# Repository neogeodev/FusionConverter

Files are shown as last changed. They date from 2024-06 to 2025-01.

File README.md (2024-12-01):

# FusionConverter

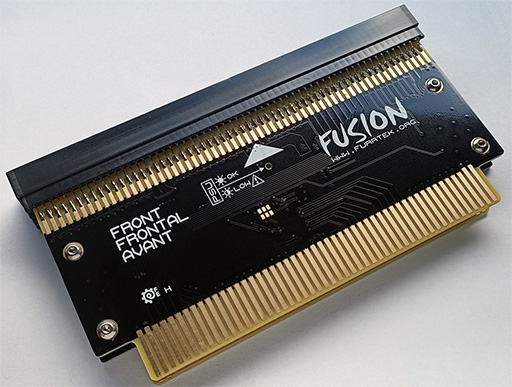
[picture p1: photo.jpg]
Fusion converter


Ready to use unbranded PCB GERBERs, BOM, Verilog and bitstream files.

Compatibility list: https://wiki.neogeodev.org/index.php?title=Fusion_converter

How to build:

* Order both PCBs with the following options: 2-layers 1.6mm thickness FR4, ENIG or hard gold fingers, edge bevelling.
* Order the components listed in `BOM.txt`. If you don't want the voltage supervision function, leave out CHA U3, R1 and D1.
* Bend the card edge connectors pins inwards to reduce their spacing and slide the boards between the rows.
* Solder everything.
* Program the CPLD with fusion_vsense.jed or fusion_vsense.svf. JTAG connections: see `JTAG.png`. The board MUST be powered externally during programming, the programming cable doesn't provide power.
* Wire the "RESET" pads on both boards together with a small wire.
* Use 8 screws and 4 standoffs to assemble both boards together.

The shell is optional. It can be printed with any method (FDM, SLA...)

# Note to JGO

* You went through the trouble of cloning an open-hardware project when you could just have used these files.
* You're not respecting the license.
* You lied about designing it yourself.
* If you cloned a device without paying attention to its open-source nature, that means you would also clone closed-source devices without caring.

From all the people who create things and share them for free: Fuck you.

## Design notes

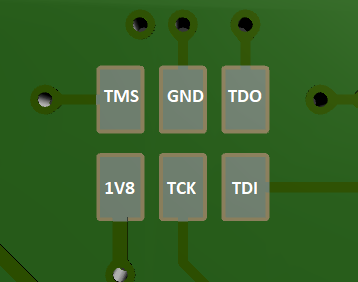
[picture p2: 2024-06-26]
JTAG.png

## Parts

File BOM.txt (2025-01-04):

CHA board:
Jx: Card edge connector 2*60pin 2.54mm pitch Sullins EZC60DCTT or EDAC 345-120-520-201
R1: Resistor 1k 0603
C1, C3-C6: MLCC 100nF 10V X7R 0603
C2: Tantalum capacitor 22uF 16V case C
U1: Dual output LDO 1.8V 3.3V AP7312-1833W6
U2: CPLD Lattice LC4064ZE-7TN100
U3: Voltage detector 4.8V APX803Lxx-48SA (xx = any)
D1: 1206 red LED

PROG board:
Jx: Card edge connector 2*60pin 2.54mm pitch Sullins EZC60DCTT or EDAC 345-120-520-201
R1: Resistor 1k 0603
C1-C3: MLCC 100nF 10V X7R 0603
C4: Tantalum capacitor 22uF 16V case C
U1, U2: Octal bus transceiver 74HC245 TSSOP20
U3: Quad 2-input AND gates 74HC08, 74AHC08 or 74HCT08 TSSOP14

Mechanical:
8x M3x4mm BHC screws, or M3x6mm if using shell
4x Hex 8mm standoffs

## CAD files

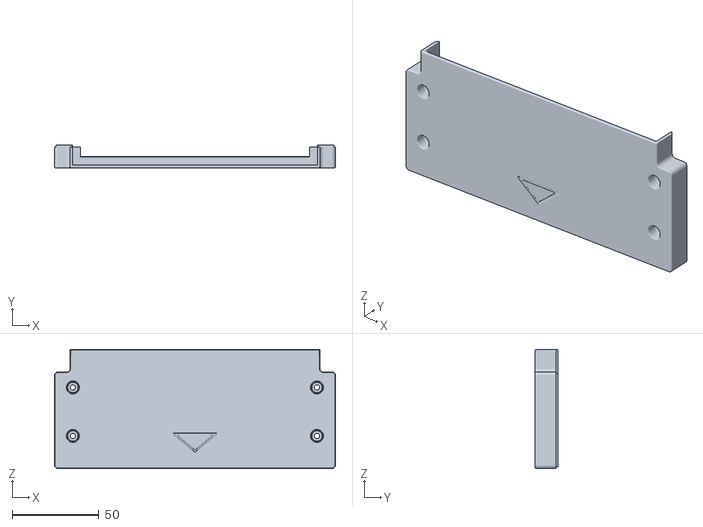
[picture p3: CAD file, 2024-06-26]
ShellA.STL
162.0 x 13.0 x 68.7

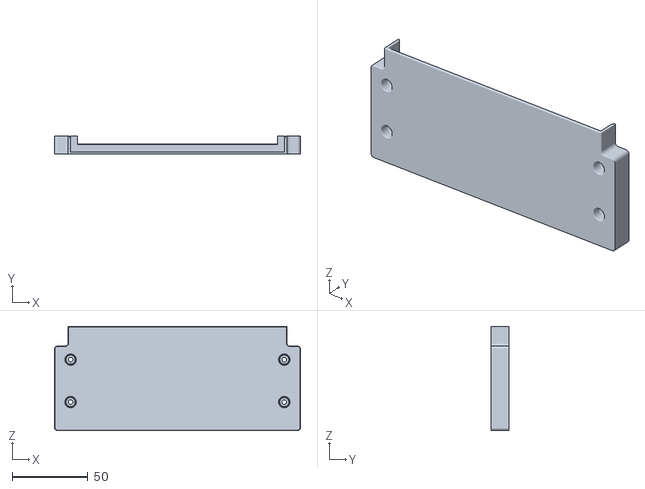
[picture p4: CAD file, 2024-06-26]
ShellB.STL
162.0 x 12.0 x 68.7

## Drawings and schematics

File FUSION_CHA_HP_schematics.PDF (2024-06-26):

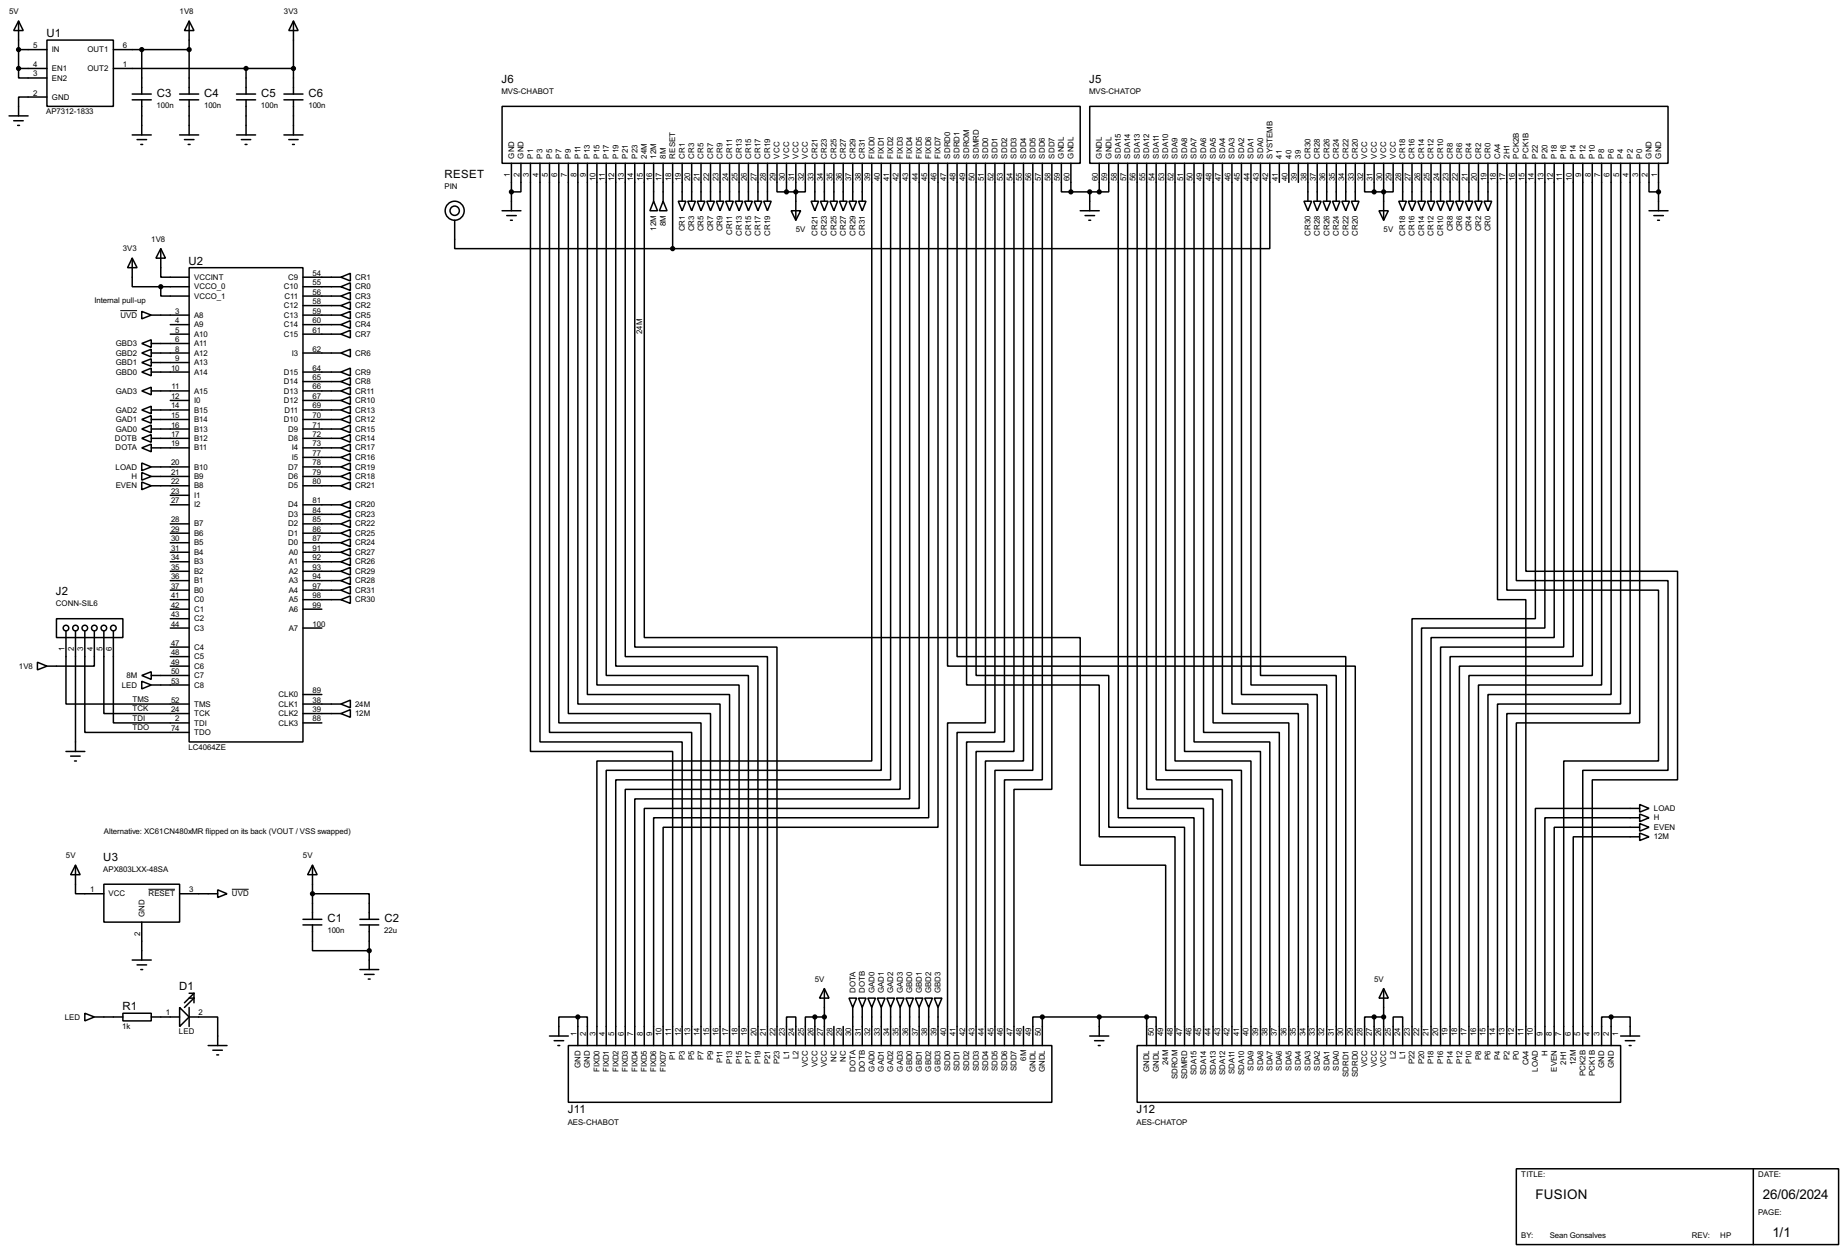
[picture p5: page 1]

8M LED TMS

TCK

Alternative: XC61CN480xMR flipped on its back (VOUT / VSS swapped)

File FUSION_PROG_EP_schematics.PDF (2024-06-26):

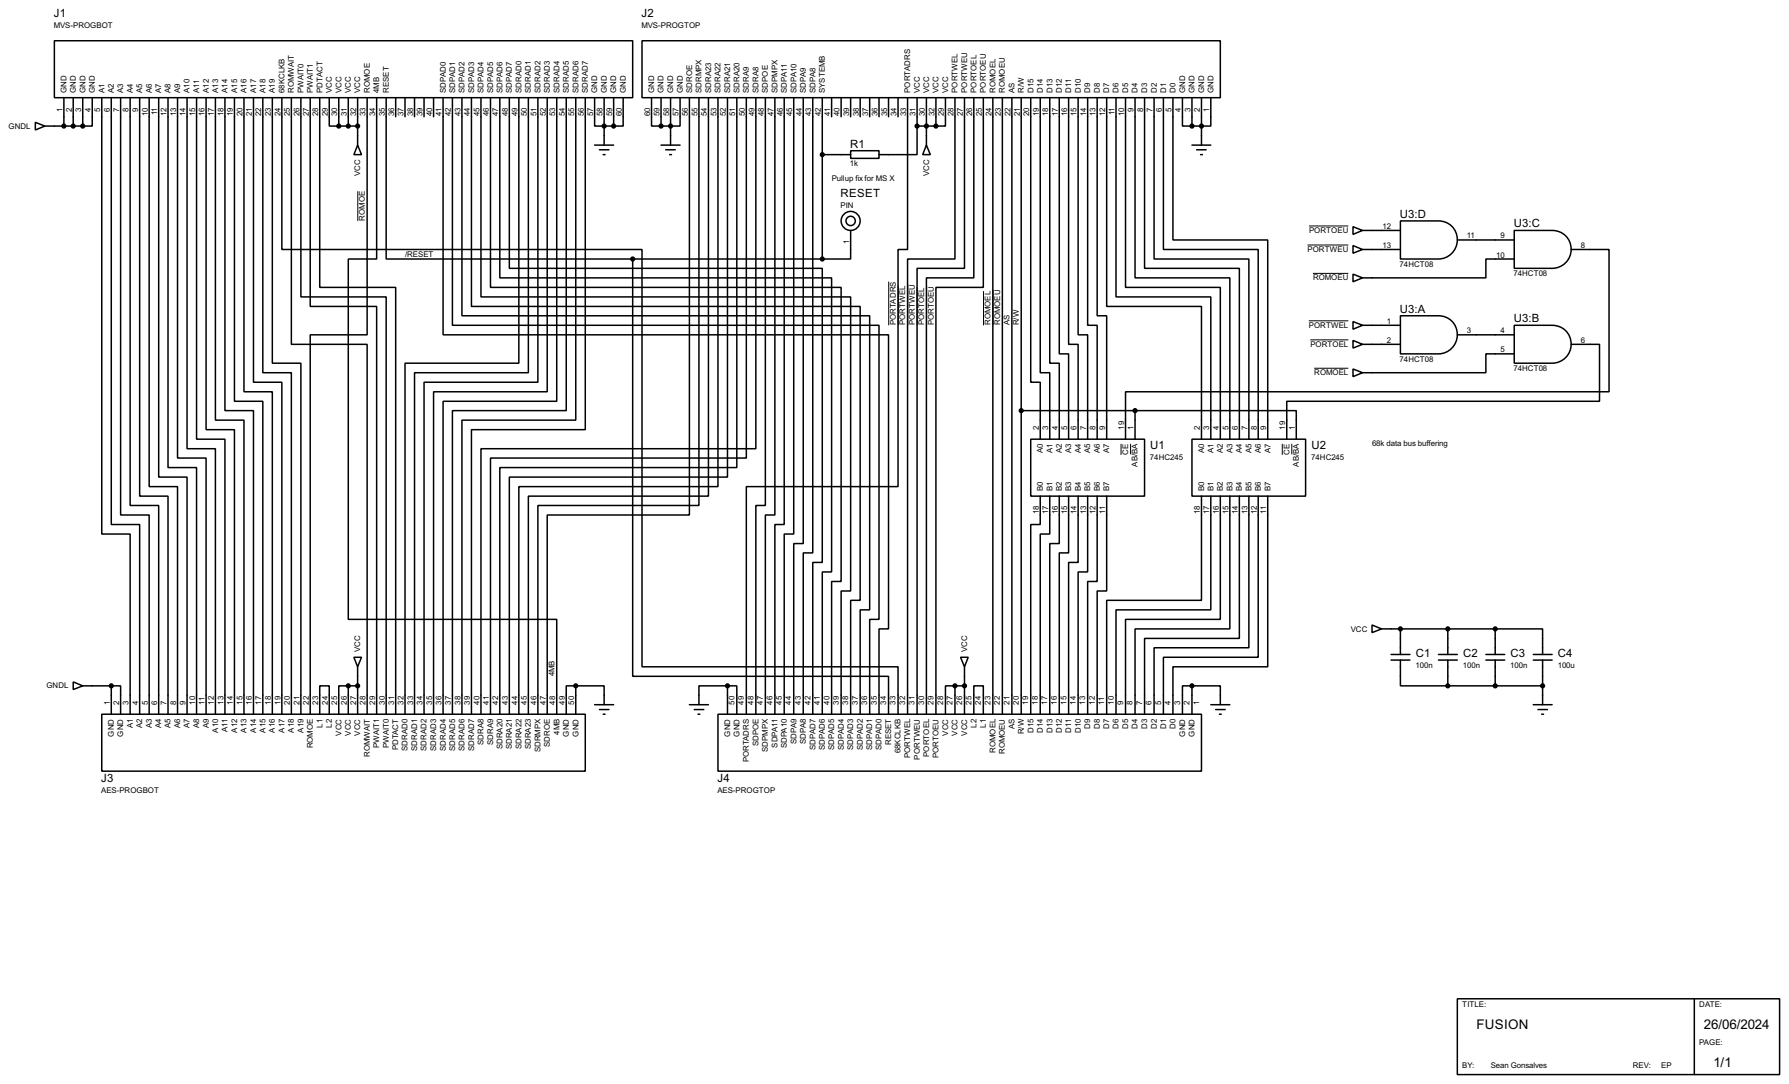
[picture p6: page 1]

Pullup fix for MS X

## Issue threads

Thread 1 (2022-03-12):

BOM

RastaJedi, 2022-03-12:
I see about 7 pads for capacitors on both boards, including the through-hole ones. I see from many pictures of your fusion that the through-hole is not populated. I still see three caps in the front, and two on the back, but the BOM has only two caps listed. I think the BOM is incomplete? Please advise =). Trying to make one for personal use.

furrtek, 2022-03-17:
BOM and JTAG info updated, sorry for the wait :)

RastaJedi, 2022-03-17:
No worries! Thanks so much for the update! Really appreciate it!

Closed 2024-12-01.

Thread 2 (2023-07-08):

Compiling the CPLD Firmware

Retrofletch, 2023-07-08:
Hello
i have built two of these and they both act the same, i get only the normal blue screen and rarely i get a verry garbled Neo geo logo trying to show.

When i tried to compile the firmware in Quartus i got many errors in regards to timings as there is no SDC file, i tried to make my own and got rid of almost all the complaints but i was more or less just making guesses so im not sure i did it correctly.

basicly im not at all confident in my compiled firmware and i suspect that is the issue as i have double checked soldering.

Is there a more complete set of quartus files to work with? or even better a confirmed and known working file to program the cpld with?

Looks like original files were made in quartus 12, i was not able to find that so i was using quartus 13, maybe thats a problem?
have tested several mvs cartidges.

reset wire is soldered in.

not sure how to proceed, any help appreciated
thanks

furrtek, 2023-07-08:
Hello,

The files are known to work, the timing warnings given by Quartus can be ignored as the clocks are well under the fmax.
Blue screen means the console wasn't able to read the program ROMs, which the CPLD doesn't mess with. Most certainly several bad contacts.

Retrofletch, 2023-07-08:
Hmm yes, but if i plug in a AES cart it will boot and all contacts both on the fusionconverter and the mvs cartridges have been cleaned, not sure what else it could be besides the cpld =/

Closed 2024-12-01.

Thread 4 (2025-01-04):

typo in BOM.txt

UNDEF2, 2025-01-04:
74HC245 should be TSSOP20, not TSSOP14.
Also, BOM shows 74HC08, but schematics show 74HCT08.

furrtek, 2025-01-04:
Fixed, thanks.

Closed 2025-01-04.

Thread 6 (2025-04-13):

JTAG footprint

bodgit, 2025-04-13:
Hello,

When programming the CPLD, presumably the 2x3 JTAG footprint on the CHA PCB is designed for some sort of pogo pin arrangement. Is there a recommended adapter for this? I can see there are cheap "burning clip" adapters on AliExpress for some pitches such as 1.27mm which looks like it might work.

Thanks

furrtek, 2025-04-14:
Hello, the footprint doesn't correspond to any particular adapter, I made a dirty custom one with veroboard and pogo pins.
You can also solder temporary wires to the pads if you're only building a few converters.
Please check `JTAG.png` for the pinout.

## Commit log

2020-12-11 Added BOM
2022-03-17 Updated BOM (sorry)
    Added JTAG pinout
2024-06-26 Printable shell
    [ShellA.STL, ShellB.STL]
